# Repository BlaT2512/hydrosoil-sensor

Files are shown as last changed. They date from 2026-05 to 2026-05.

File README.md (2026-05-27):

# HydroSensor

This repository is part of HydroSoil, and contains the latest firmware and some revisions of CAD designs for HydroSensor and HydroSensor Pro. 

HydroSensor's are ultra-low-power devices, running custom embedded firmware designed to communicate with the HydroSoil network.

HydroSensor's are engineered for high-reliability, minimal loss of data, and long battery life. The firmware features:

- Simple cryptographic hashing of REST payloads for API security & replay protection, using built-in RF physical noise registers (`ESP.random()`)
- Tracking of internal battery and soil moisture level, as well as ambient light, temperature and humidity for Pro sensor
- Non-volatile data backups to local disk with tracking of timestamps. During times of unstable network connection, HydroSensor's seemlessly continue readings locally and upload all stored readings when connection is restored, ensuring that virtually no data is lost
- Usage of internal RTC RAM cache to store a running clock in relation to failed network requests, to bypass the lack of a physical RTC, and avoid network/battery overhead of communicating with NTP servers. A CRC32 checksum algorithm is also use d to validate integrity of the RAM on boot cycles
- Dynamic sleep times to intelligently conserve power, calculated based off of environment change delta reading-over-reading, readings compared to normal thresholds, and number of failed requests if server is unreachable
- A "dumb edge, smart cloud" pattern is used in the ecosystem in order to offload processing of data to the HydroSoil cloud, including calculation of dynamic sleep time and conversion of raw sensor readings to usable data.
- RTC RAM cache is used for time data as it is frequently written to in order to preserve silicon wear (limit of about 100,000 writes), and filesystem storage is used for data backup as it is more persistent, and writes are much less frequent - only on network failure

## Tech Stack
The microcontroller the firmware runs on is an Espressif ESP-12F chip, a single-core RISC architecture. The chip is run at 80MHz to preserve battery.
The microcontroller is wired to:
- 1x ADS1115 (a 16-bit ADC over I2C chip, used for readings from the soil moisture sensor)
- 1x SHT-31D (I2C digital temperature and humidity sensor)
- 1x TSL2591 (I2C digital visible & infrared light sensor)

The firmware is written in C++ and utilises PlatformIO core and Espressif 8266 development package. The firmware also uses LittleFS for communication with filesystem storage, WiFiManager for emitting a captive portal when WiFi is not configured, and standard Adafruit libraries for each peripheral used listed above.

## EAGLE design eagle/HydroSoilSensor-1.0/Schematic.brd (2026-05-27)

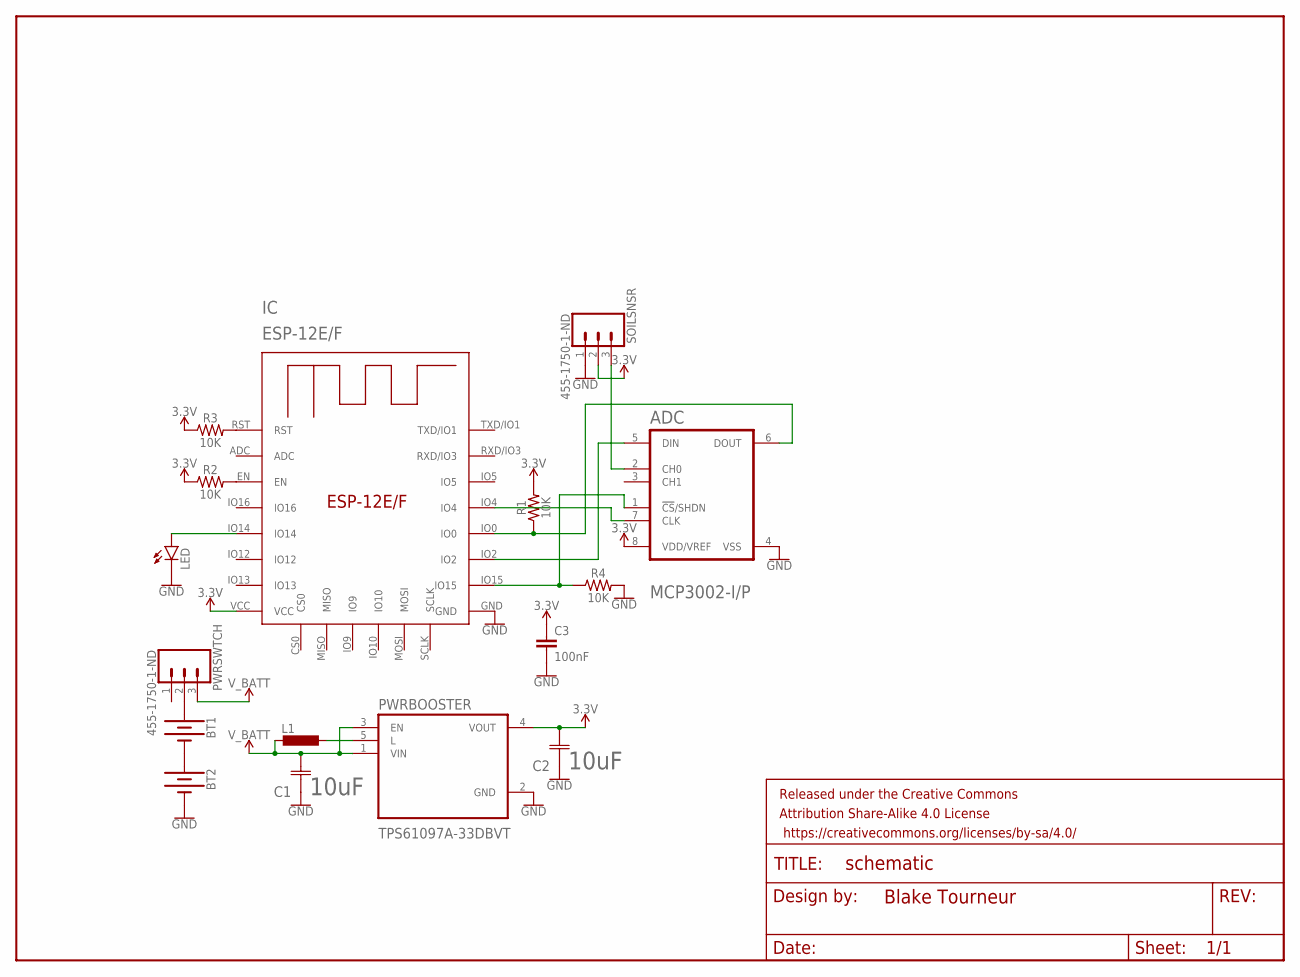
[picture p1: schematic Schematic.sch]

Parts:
ADC: MICROCHIP_MCP3002-I-PMICROCHIP_MCP3002-I-P_0_0; MICROCHIP_MCP3002-I-P_0
BT1, BT2: BATTERY-AA
C1, C2: 10uF; CAPC3216X180N
C3: 100nF; C2.5-3
FRAME1: FRAME-LETTERNO_PACKAGE; DUMMY
IC: ESP-12E/F; ESP-12E
L1: DO3316P
LED: LED3MM
PWRBOOSTER: TPS61097A-33DBVT; SOT95P280X145-5N
PWRSWTCH: 455-1750-1-ND; 1X03
R1, R2, R3, R4: 10K; 0402-TIGHT
SOILSNSR: 455-1750-1-ND; 1X03

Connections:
3.3V: ADC.8 (VDD/VREF), C2.2 (C2), C3.1, IC.VCC, PWRBOOSTER.4 (VOUT), R1.2, R2.1, R3.1, SOILSNSR.2
ASENS0: ADC.2 (CH0), SOILSNSR.3
COIL: L1.2, PWRBOOSTER.5 (L)
CS: ADC.1 (!CS!/SHDN), IC.IO15, R4.1
GND: ADC.4 (VSS), BT2.GND@1 (-), C1.1 (C1), C2.1 (C1), C3.2, IC.GND, LED.K (C), PWRBOOSTER.2 (GND), R4.2, SOILSNSR.1
IO0: ADC.6 (DOUT), IC.IO0, R1.1
LED: IC.IO14, LED.A
MCPCLK: ADC.7 (CLK), IC.IO4
MCPDIN: ADC.5 (DIN), IC.IO2
unnamed: BT1.GND@1 (-), BT2.PWR@1 (+)
unnamed: BT1.PWR@1 (+), PWRSWTCH.2
unnamed: IC.EN, R2.2
unnamed: IC.RST, R3.2
V_BATT: C1.2 (C2), L1.1, PWRBOOSTER.1 (VIN), PWRBOOSTER.3 (EN), PWRSWTCH.3

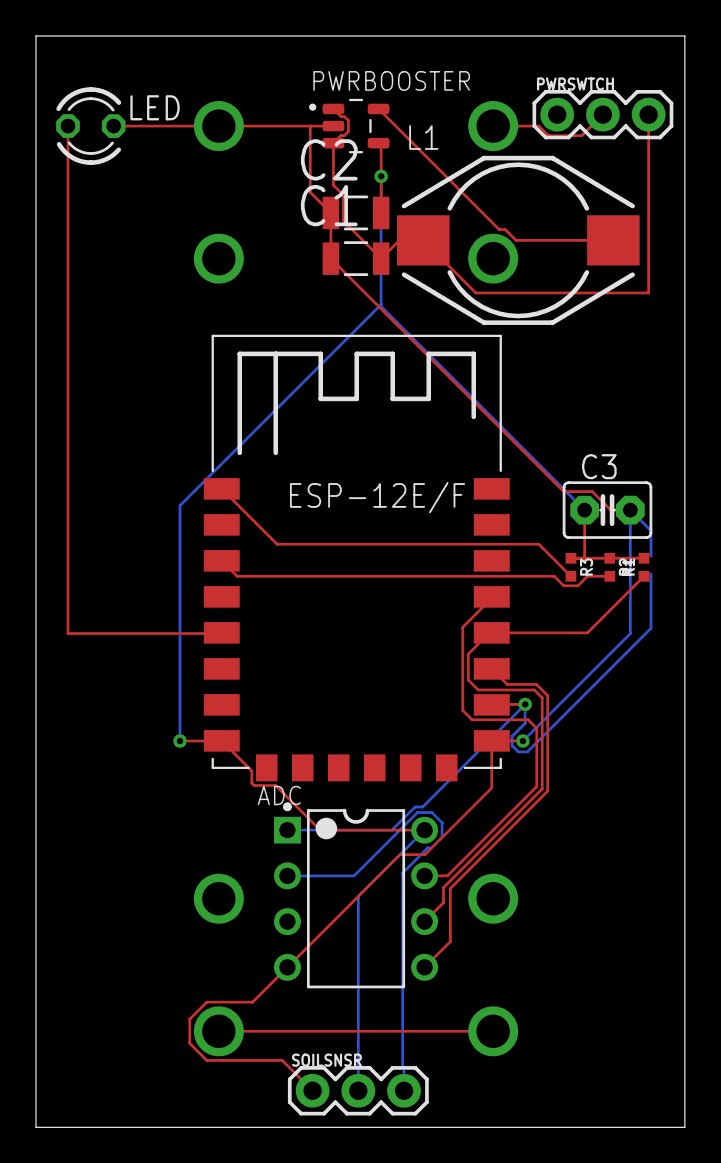
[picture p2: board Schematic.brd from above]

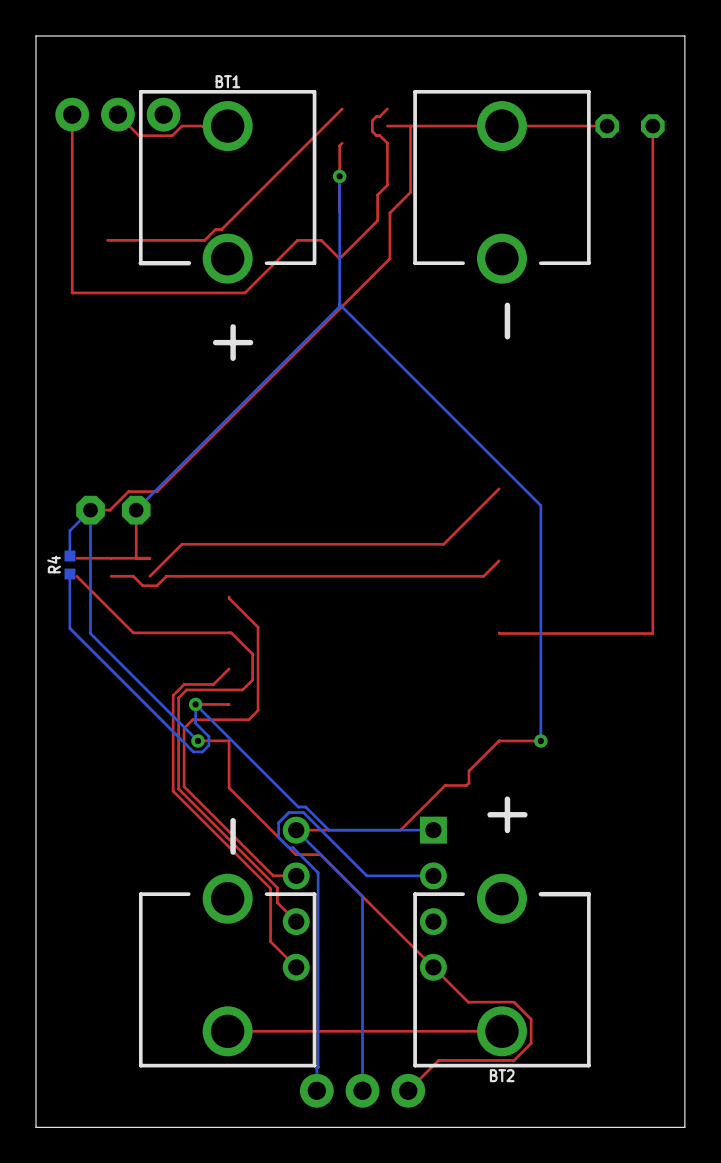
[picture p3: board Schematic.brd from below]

Board: 2 copper layers, 36.0 x 60.6 mm, 17 parts (3 on the bottom side), 14 nets.

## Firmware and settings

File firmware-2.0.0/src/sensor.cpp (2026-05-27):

/**
 * sensor.cpp
 * Manages update checking, collection of sensor data, and communication to server
 */

#include "sensor.hpp"

#define DEBUG_MODE false // Outputs logs to serial if true
#define LOG_SERIAL if (DEBUG_MODE) Serial

ADC_MODE(ADC_VCC);

#ifdef HARDWARE_PRO
Sensor::Sensor() : m_ads(), m_sht31(), m_tsl2591() {}
#else
Sensor::Sensor() : m_ads() {}
#endif // HARDWARE_PRO

// MARK: RTC Memory
uint32_t Sensor::calculateChecksum(const uint8_t* data, size_t length) const {
    // Standard calculation of CRC32
    // Inspired by https://stackoverflow.com/questions/31585116/crc32-calculation-with-crc-hash-at-the-beginning-of-the-message-in-c
    uint32_t crc = 0xFFFFFFFF;
    while (length--) {
        crc ^= *data++;
        for (uint8_t i = 0; i < 8; i++) {
            if (crc & 1) crc = (crc >> 1) ^ 0xEDB88320;
            else crc >>= 1;
        }
    }
    return ~crc;
}

void Sensor::readCache() {
    if (ESP.rtcUserMemoryRead(64, (uint32_t*)&m_cache, sizeof(m_cache))) {
        uint32_t checksum = calculateChecksum(((uint8_t*)&m_cache) + 4, sizeof(m_cache) - 4);
        if (checksum != m_cache.checksum) {
            m_cache.lastReadingsPresent = false;
            m_cache.thresholdsPresent = false;
            m_cache.clock = 0;
        } else {
            m_cache.clock += (m_sleepInterval / 1000000); // Accumulate time just slept
            LOG_SERIAL.println("Using RTC cache");
        }
    }
}

void Sensor::writeCache() {
    m_cache.checksum = calculateChecksum(((uint8_t*)&m_cache) + 4, sizeof(m_cache) - 4);
    ESP.rtcUserMemoryWrite(64, (uint32_t*)&m_cache, sizeof(m_cache));
}

bool Sensor::parseNewThresholds(Stream& jsonStream) {
    JsonDocument doc;
    DeserializationError error = deserializeJson(doc, jsonStream);

    if (error) {
        LOG_SERIAL.printf("Failed to parse JSON response: %s\n", error.c_str());
        return false;
    }

    if (doc["thresholdsPresent"]) {
        m_cache.moistureLow = doc["moisture_low"] | 0;
        m_cache.moistureHigh = doc["moisture_high"] | 0;

#ifdef HARDWARE_PRO
        m_cache.tempLow  = doc["temp_low"] | 0.0f;
        m_cache.tempHigh = doc["temp_high"] | 0.0f;
        m_cache.luxLow   = doc["lux_low"] | 0;
        m_cache.luxHigh  = doc["lux_high"] | 0;
#endif // HARDWARE_PRO

        m_cache.thresholdsPresent = true;
        LOG_SERIAL.println("Parsed response JSON thresholds");
        return true;
    }
    
    return false;
}

// MARK: Initialise
void Sensor::init() {
    // Status indicator
    pinMode(LED_GPIO, OUTPUT);
    digitalWrite(LED_GPIO, HIGH);

    // Initialise debug logging
    LOG_SERIAL.begin(115200);
    LOG_SERIAL.printf("\n--- HydroSensor Initialisation [v%s] ---\n\n", FIRMWARE_VERSION);

    // Attempt to populate cache with RTC cache data
    readCache();

    // Initialise LittleFS for offline backup in case we fail to send sensor data
    if (!LittleFS.begin()) LOG_SERIAL.println("[ERROR] Failed to initialise LittleFS, local backup disabled.");

    // Initialise network via WiFiManager
    WiFiManager wifiManager;
    wifiManager.setAPStaticIPConfig(IPAddress(10,0,1,1), IPAddress(10,0,1,1), IPAddress(255,255,255,0));
    wifiManager.setAPCallback(Sensor::configModeCallback);
    wifiManager.setConfigPortalTimeout(180);

    if (!wifiManager.autoConnect(AP_NAME)) {
        LOG_SERIAL.println("[ERROR] Network authentication timeout. Entering deep sleep.");
        enterDeepSleep();
    }

    LOG_SERIAL.printf("Connected to WiFi!\nIP: %s\nMAC: %s.\n\n", WiFi.localIP().toString().c_str(), WiFi.macAddress().c_str());

    // Initialise I2C sensors
    m_adsOnline = m_ads.begin();
    if (!m_adsOnline) LOG_SERIAL.println("[ERROR] ADC Bus Offline!");

#ifdef HARDWARE_PRO
    m_shtOnline = m_sht31.begin(0x44);
    if (!m_shtOnline) LOG_SERIAL.println("[ERROR] Temp/Humidity Sensor Offline!");

    m_tslOnline = m_tsl2591.begin();
    if (!m_tslOnline) LOG_SERIAL.println("[ERROR] Light Sensor Offline!");
#endif // HARDWARE_PRO
}

// MARK: OTA Updates
bool Sensor::checkUpdates() {
    ESPhttpUpdate.rebootOnUpdate(false);
    t_httpUpdate_return response = ESPhttpUpdate.update(m_updateClient, UPDATE_HOST, FIRMWARE_VERSION);

    switch (response) {
        case HTTP_UPDATE_OK:
            LOG_SERIAL.println("[OTA] Firmware updated successfully!");
            return true;
        case HTTP_UPDATE_FAILED:
            LOG_SERIAL.printf("[OTA] [ERROR] OTA failed (%d): %s.\n", ESPhttpUpdate.getLastError(), ESPhttpUpdate.getLastErrorString().c_str());
            break;
        case HTTP_UPDATE_NO_UPDATES:
            LOG_SERIAL.println("[OTA] No update required.\n");
            break;
    }
    return false;
}

// MARK: Cache Buffer
void Sensor::appendToBuffer(const String& dataLine) {
    File bufferFile = LittleFS.open(BUFFER_FILE, "a");
    if (!bufferFile) {
        LOG_SERIAL.println("[FS] [ERROR] Failed to open buffer file for writing.");
        return;
    }

    if (bufferFile.println(dataLine)) {
        LOG_SERIAL.println("[FS] Sensor data cached.");
    } else {
        LOG_SERIAL.println("[FS] [ERROR] Failed to write sensor data to flash buffer.");
    }
    bufferFile.close();
}

bool Sensor::dispatchBuffer(HTTPClient& http) {
    if (!LittleFS.exists(BUFFER_FILE)) return true;

    File bufferFile = LittleFS.open(BUFFER_FILE, "r");
    if (!bufferFile) return true;

    String batch = "{ \"time\": \"" + String(m_cache.clock) + "\", \"backlog\": [";
    uint8_t count = 0;

    while (bufferFile.available()) {
        String payload = bufferFile.readStringUntil('\n');
        payload.trim();
        
        if (payload.length() > 0) {
            if (count > 0) batch += ", ";
            batch += payload;
            count++;
        }
    }
    bufferFile.close();
    batch += "]}";

    if (count > 0) {
        LOG_SERIAL.printf("[FS] Sending %u cached telemetry readings to server.", count);
        
        int response = http.POST(batch);
        
        if (response == 201) {
            LOG_SERIAL.println("[FS] Sent cached telemetry buffer to server.");
            LittleFS.remove(BUFFER_FILE);
        } else {
            LOG_SERIAL.printf("[FS] [ERROR] Failed to send cached telemetry buffer. Status: %d.\n", response);
            return false;
        }
    }
    return true;
}

// MARK: Authentication
String Sensor::generateRequestId() const {
    char buffer[17];
    uint32_t r1 = ESP.random();
    uint32_t r2 = ESP.random();
    sprintf(buffer, "%08X%08X", r1, r2);
    return String(buffer);
}

String Sensor::generateApiKey(const String& requestId) const {
    static constexpr uint32_t SECRET = 7291034;
    uint32_t hash = SECRET;
    // Simple bitwise hash
    for (size_t i = 0; i < requestId.length(); i++) {
        hash = (hash << 5) + hash + requestId[i];
    }
    char buffer[16];
    itoa(hash, buffer, 36);
    return String(buffer);
}
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

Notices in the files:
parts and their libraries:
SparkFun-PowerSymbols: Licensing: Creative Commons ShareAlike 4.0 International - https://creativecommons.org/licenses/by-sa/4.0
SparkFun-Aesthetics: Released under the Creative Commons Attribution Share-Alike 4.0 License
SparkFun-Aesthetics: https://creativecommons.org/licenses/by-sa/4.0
